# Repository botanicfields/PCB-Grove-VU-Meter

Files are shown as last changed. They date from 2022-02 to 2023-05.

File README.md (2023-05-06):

# PCB-Grove-VU-Meter
VU Meters into the Grove of M5

# オーディオレベルメーター用Grove(M5)接続基板
　ステレオオーディオ信号を、レベルメーター用のアナログ電圧信号に変換するプリント基板です。アナログ信号2本とM5Stack用の5V電源を、Groveコネクタから出力します。M5StackのLCDにVUメーターのように表示するサンプルプログラムを用意しています。

### サンプルプログラムの動作不良について
(2023/5/6) BF-037.inoは、以下の環境でコンパイルできました。しかしばがら、ADCによるオーディオ信号の取り込みが安定せず、使用に耐えない状況です。
- Arduino IDE 2.1.0
- Boards Manager:  
M5Stack by M5Stack official 2.0.7
- Library:  
M5Stack by M5Stack 0.4.3  
M5GFX 0.1.6

[内容物]  
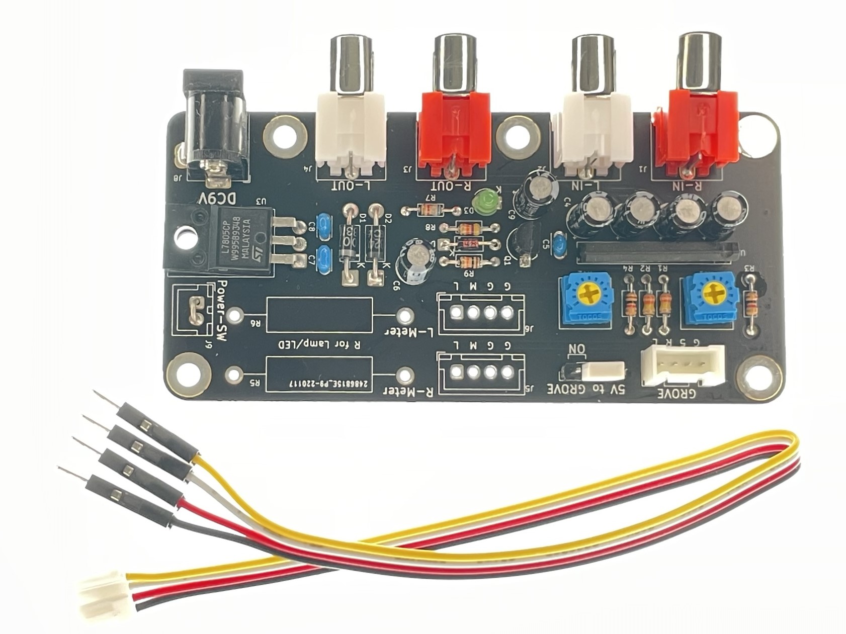
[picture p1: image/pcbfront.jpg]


動作例（YouTube）: [Audio level (VU/McIntosh) meters into the Grove of M5Stack](https://youtu.be/Pwd8X57_v_Q)

委託販売（スイッチサイエンス）:  [オーディオレベルメーター用Grove(M5)接続基板](https://www.switch-science.com/catalog/7947/)

## 安全上の注意事項
- 異常の場合、躊躇なくDCプラグを抜いてください（基板上のレギュレータ(U3)が触れないぐらい発熱しているなど）。その上で原因を取り除いてください。
- Groveへの5V出力は、必要な場合以外は、ジャンパピンJP3で切り離してください。特に電源が3.3Vの装置に5Vを供給すると焼損など事故の原因となります。
- 本基板からの5VとM5Stack側からの5Vは共存できません。僅かな電圧差から大電流が流れ、素子の発熱による火傷や、M5Stackの故障の原因になります。
- M5StackへのUSB-C以外の5V電源供給は推奨されていません。本基板の機能を含め、M5Stackへの直接の5V供給は自己責任です。

## 特徴
- オーディオ信号を整流し対数圧縮する専用LSI(ROHM BA6138)を使用しています。
- 基板上の半固定抵抗でフルスケールを調整できます。
- M5Stackの標準ボトムのピンソケットに接続するためのケーブルを添付しています。
- M5Stackへ5V電源を供給でき、スタンドアロン動作ができます。
- 左右2系統のRCAピンジャックが各々2個(In, Out)あり、RCAケーブルを中継できます。

## 注意事項
- 本基板は測定器ではありません。PCオーディオなどの手軽なオーディオ環境で見た目を楽しむための小物（ガジェット、ウィジェット、アクセサリ）です。サンプルプログラムの目盛も全くの飾りです。  
- BA6138は入力抵抗も2kΩ程度と低く、音質への影響は小さくないものと思われます。

## Groveコネクタへの5V電源供給のON/OFF
　本基板のジャンパピンJP3でGroveコネクタへの5V供給のON/OFFを設定します。JP3の切替は、DCプラグを抜いて実施ください。出荷時はOFFです。

| JP3 | Grove 5Vピン | M5Stackの電源 | 用途 |
|:-:|:- |:- |:- |
| OFF | 接続なし | USB-C、またはバッテリから供給(*1) | プログラム書き込み、シリアルモニターの利用など |
| ON  | 5Vを供給 | 本基板から供給(*2) | M5Stackをスタンドアロンで使用など |

(*1) JP3をOFFに設定してから、本基板のDCプラグを差し込んでください。  
(*2) JP3をONに設定する際は、USB-Cケーブルを取り外し、M5Stackを電源OFFとしてから、本基板のDCプラグを差し込んでください。バッテリ動作中のM5Stackは、電源/リセットボタンを2回押すことで電源OFFにできます。

[USB-C接続あり]  
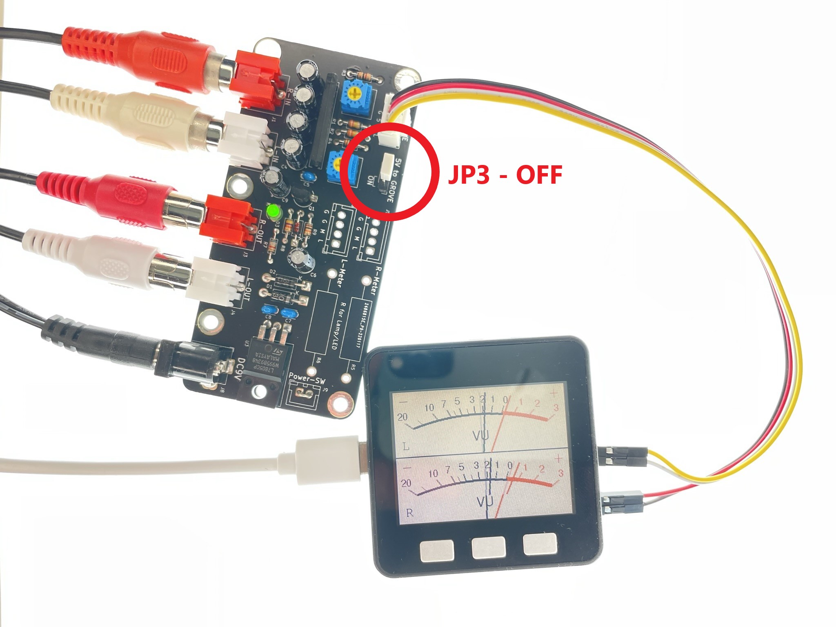
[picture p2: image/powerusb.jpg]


[Groveから電源供給]  
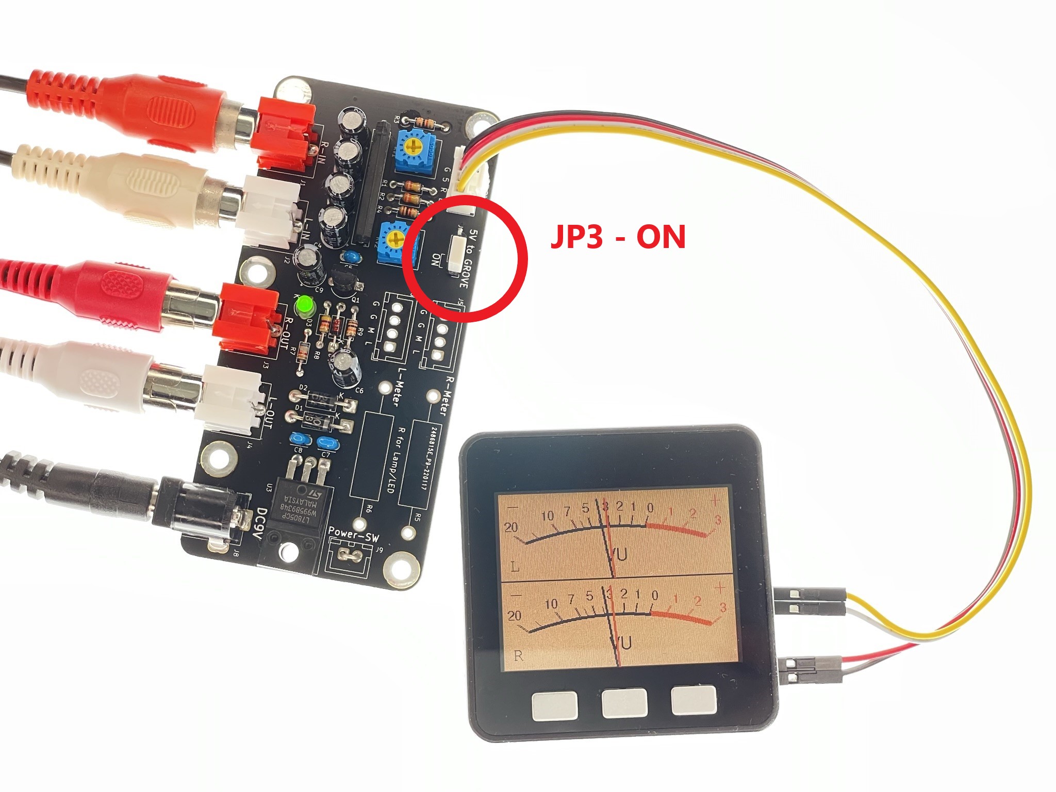
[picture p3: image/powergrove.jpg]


## 仕様
- 外形寸法: 92x44mm
- 電源入力: DCジャック（DC 9V）
- 信号入力: RCAピンジャック（L/R, オーディオラインレベル）
- 信号出力: Groveコネクタ（アナログ2本）
- 電源出力: Groveコネクタ（DC 5V）

## 内容物
- プリント基板（完成品）
- Grove-4ピン-ジャンパオスケーブル [SEEED-110990210](https://www.switch-science.com/catalog/6245/)　※5本入のうちの１本です
- 説明書

## 使用方法
- 電源（ACアダプタ等）は添付しません。別途ご用意ください。  
例：秋月電子通商　スイッチングＡＣアダプター　９Ｖ１．３Ａ [AD-B90P130](https://akizukidenshi.com/catalog/g/gM-11998/)
- 電源スイッチはありません。入力や出力を接続し、設定を確かめてからDCプラグを差し込んでください。
- RCAジャックは2系統（赤・白）あり、各々2個が並列になっています。便宜上、基板シルクにはIN, OUTと表示しています。
- Groveの出力信号はアナログ電圧です。M5StackのPort A(I2C)には接続できません。M5Stackのボトムの端子に接続してください。

[サンプルプログラム使用時のM5Stackへの接続]  
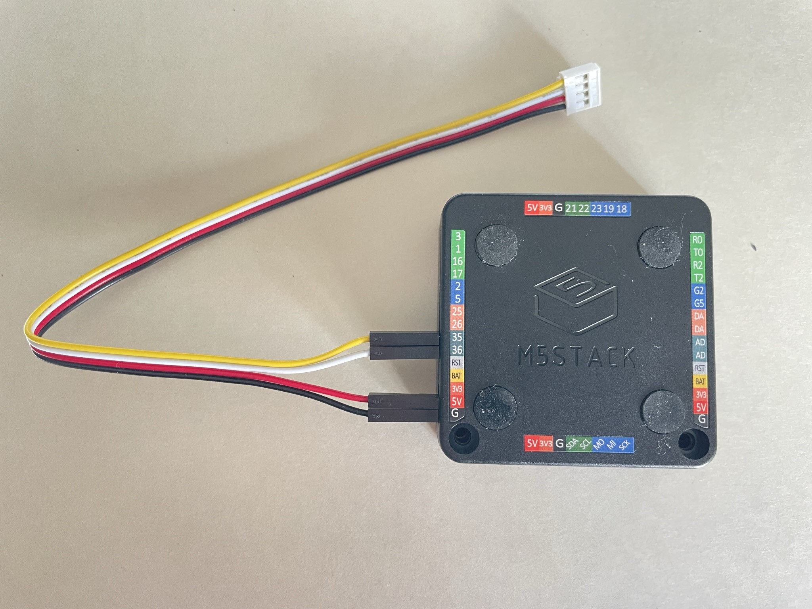
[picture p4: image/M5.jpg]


|Grove|M5Stack|
|:-:|:-:|
|L  |GPIO35|
|R  |GPIO36|
|5V |5V |
|GND|GND|

- 基板上の半固定抵抗は、ご使用の環境で再調整ください。調整には小型のプラスドライバが必要です。

### 出荷時の調整の環境
- Windows11
- USB DAC: Sound Blaster Digital Music Premium HD(SB1240) [製品情報](https://jp.creative.com/p/sound-blaster/sound-blaster-digital-music-premium-hd)  
※安定動作のためには、Windows10 64bit用ドライバーの適用が有効な様です。[ドライバーダウンロード](https://jp.creative.com/support/downloads/download.asp?Product_ID=19829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)
- YouTube Music: Audiolab 2014: Audio Test Tones: [1kHz 0dB](https://music.youtube.com/watch?v=_XMpb9BjGgE&feature=share)
- VUメーターが-5VUを示す様に調整（一般音源のメーターの振れが適当になる位置）

[入力信号-3dB(L/R)に対する出力(L/R)の例]  
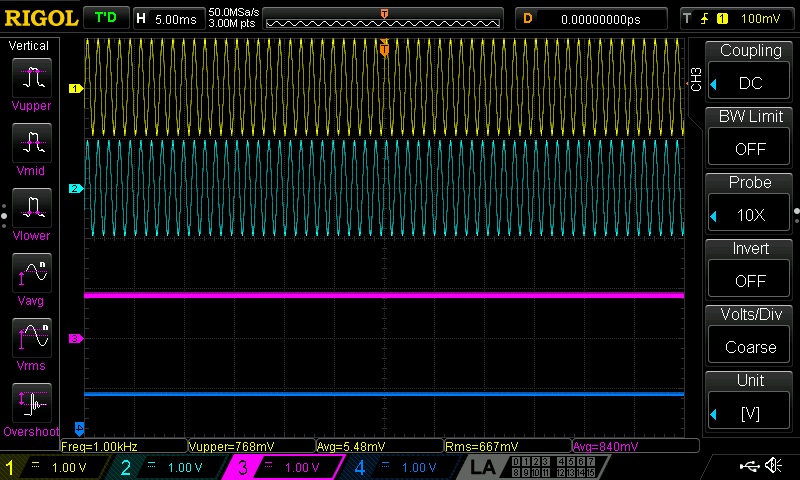
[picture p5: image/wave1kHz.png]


[音楽信号入力(L/R)に対する出力(L/R)の例]  
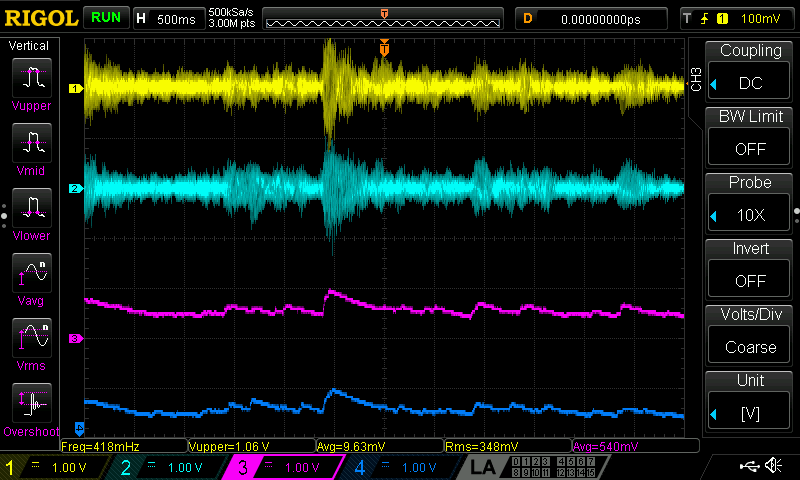
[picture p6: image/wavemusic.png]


## ご参考
- ROHM BA6138  
aitendo扱い レベルメーターアンプ [BA6138](https://www.aitendo.com/product/11726)
データシート[BA6138](http://aitendo3.sakura.ne.jp/aitendo_data/product_img/ic/audio/BA6138/BA6138.pdf)
- 基板上の、以下の部品等は未使用です。  
J5, J6, J9（短絡済）, JP1, JP2, R5, R6

[基板裏面]  
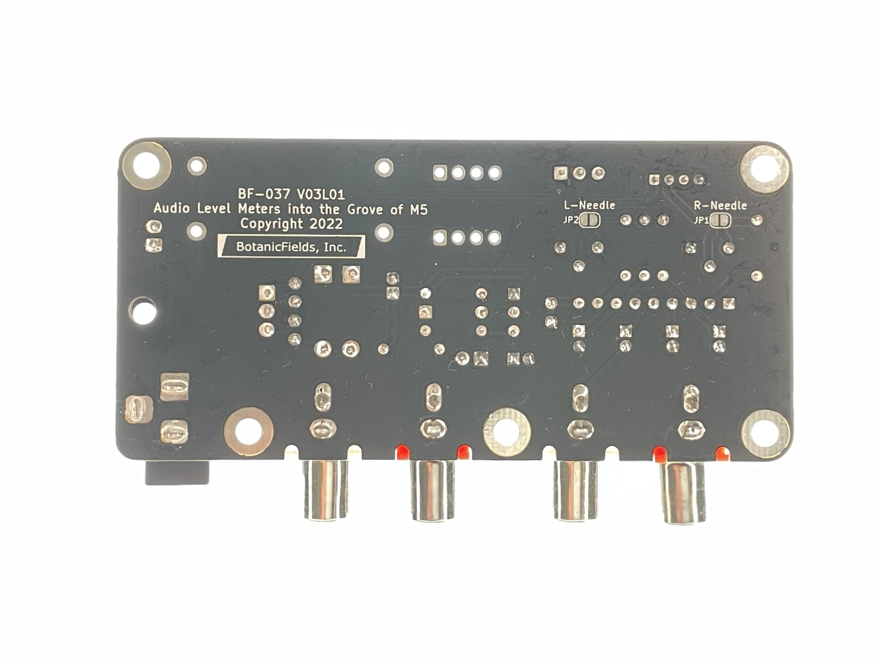
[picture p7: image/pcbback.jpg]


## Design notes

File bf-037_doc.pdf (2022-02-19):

BF-037 E01

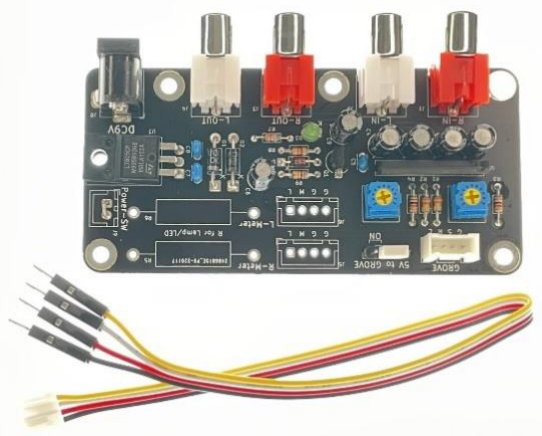
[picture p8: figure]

1 | Copyright 2022 BotanicFields, Inc.

## オーディオレベルメーター用 Grove(M5)接続基板

ステレオオーディオ信号を、レベルメーター用のアナログ 電圧信号に変換するプリント基板です。アナログ信号 2 本と M5Stack 用の 5V 電源を、Grove コネクタから出力します。

[サンプルプログラム、詳細情報]
https://github.com/botanicfields/PCB-Grove-VU-Meter

## 安全上の注意事項

⚫ | 異常の場合、躊躇なく DC プラグを抜いてください（基板上のレギュレータ(U3)が触れないぐ
| らい発熱しているなど）。その上で原因を取り除いてください。
⚫ | Grove への 5V 出力は、必要な場合以外は、ジャンパピン JP3 で切り離してください。特に電
| 源が 3.3V の装置に 5V を供給すると焼損など事故の原因となります。
⚫ | 本基板からの 5Vと M5Stack 側からの 5Vは共存できません。僅かな電圧差から大電流が流れ、
| 素子の発熱による火傷や M5Stack の故障の原因になります。
⚫ | M5StackへのUSB-C以外の5V電源供給は推奨されていません。本基板の機能を含め、M5Stack
| への直接の 5V 供給は自己責任です。
1. 仕様
⚫ | 外形寸法: 92x44mm
⚫ | 電源入力: DC ジャック（DC 9V）
⚫ | 信号入力: RCA ピンジャック（L/R, オーディオラインレベル）
⚫ | 信号出力: Grove コネクタ（アナログ 2 本）
⚫ | 電源出力: Grove コネクタ（DC 5V）
2. 内容物
⚫ | プリント基板（完成品）
⚫ | Grove-4 ピン-ジャンパオスケーブル
⚫ | 説明書（本書）
3. 使用方法
⚫ | 電源（AC アダプタ等）は添付しません。別途ご用意ください。
| （例）秋月電子通商 M-11998 スイッチングＡＣアダプター ９Ｖ１．３Ａ [AD-B90P130]
⚫ | 電源スイッチはありません。入力や出力を接続し、設定を確かめてから DC プラグを差し込ん
| でください。
⚫ | RCA ジャックは 2 系統（赤・白）あり、各々2 個が並列になっています。便宜上、基板シルク

BF-037 E01

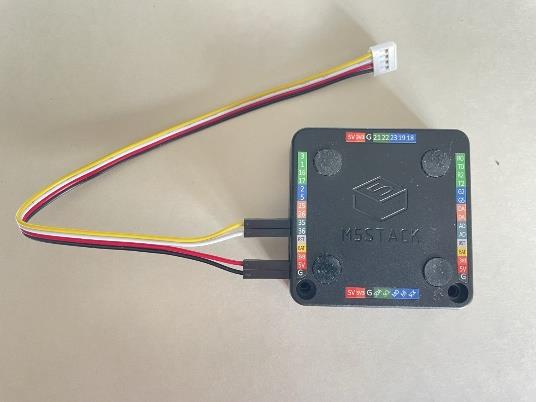
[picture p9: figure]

2 | Copyright 2022 BotanicFields, Inc.

には IN, OUT と表示しています。
⚫ | Grove の出力信号はアナログ電圧です。M5Stack の Port A(I2C)には接続できません。M5Stack
| のボトムの端子に接続してください。
⚫ | Grove コネクタへの 5V 電源供給の ON/OFF は、ジャンパピン JP3 で設定します。JP3 の設定
| 変更は、DC プラグを抜いて実施ください。出荷時は OFF です。
JP3 | Grove 5V ピン | M5Stack の電源 | 用途
OFF | 接続なし | USB-C、またはバッテリから 供給(*1) | プログラムの書き込み、シリアルモニ ターの利用など
ON | 5V を供給 | 本基板から供給(*2) | M5Stack をスタンドアロンで使用など

(*1) JP3 を OFF に設定してから、本基板の DC プラグを差し込んでください。
(*2) JP3 を ON に設定する際は、USB-C ケーブルを取り外し、M5Stack を電源 OFF としてから、本基 板の DC プラグを差し込んでください。バッテリ動作中の M5Stack は、電源/リセットボタンを 2 回押 すことで電源 OFF にできます。

[サンプルプログラム使用時の接続]
右の表に従って、添付のケーブルを
M5Stack のボトムの端子に接続してく
ださい。

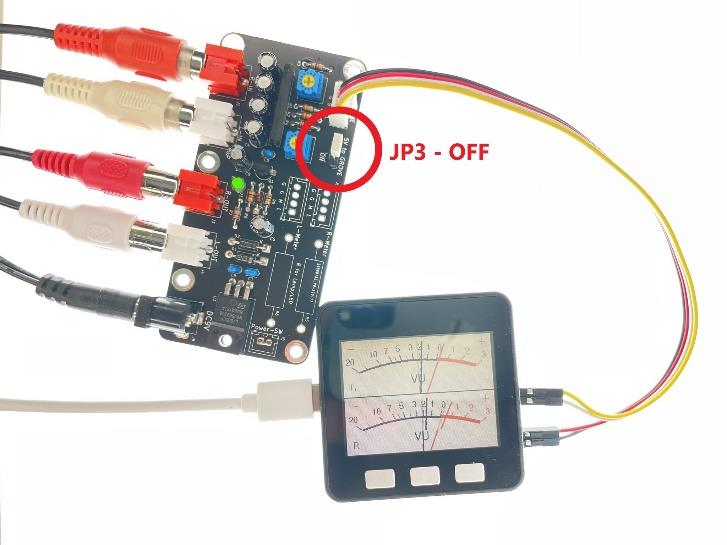
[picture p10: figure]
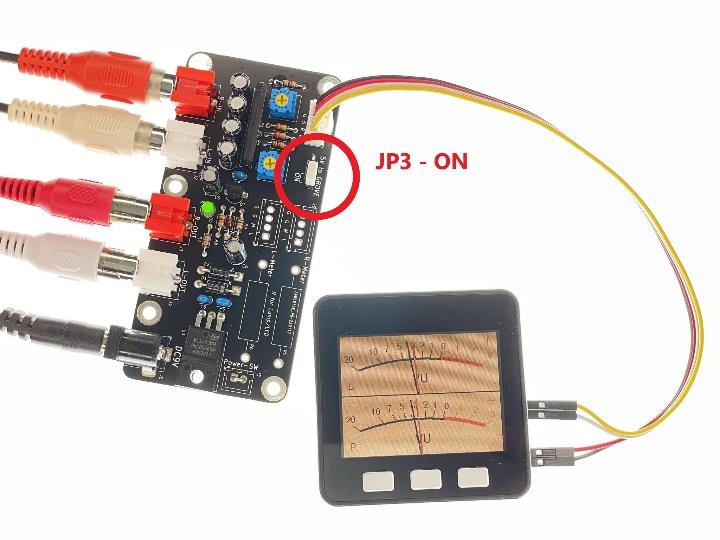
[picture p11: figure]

[USB-C 接続時の設定] | [Grove から 5V を供給する設定]

以上

Grove | M5Stack
L R 5V GND | GPIO35
| GPIO36
| 5V
| GND

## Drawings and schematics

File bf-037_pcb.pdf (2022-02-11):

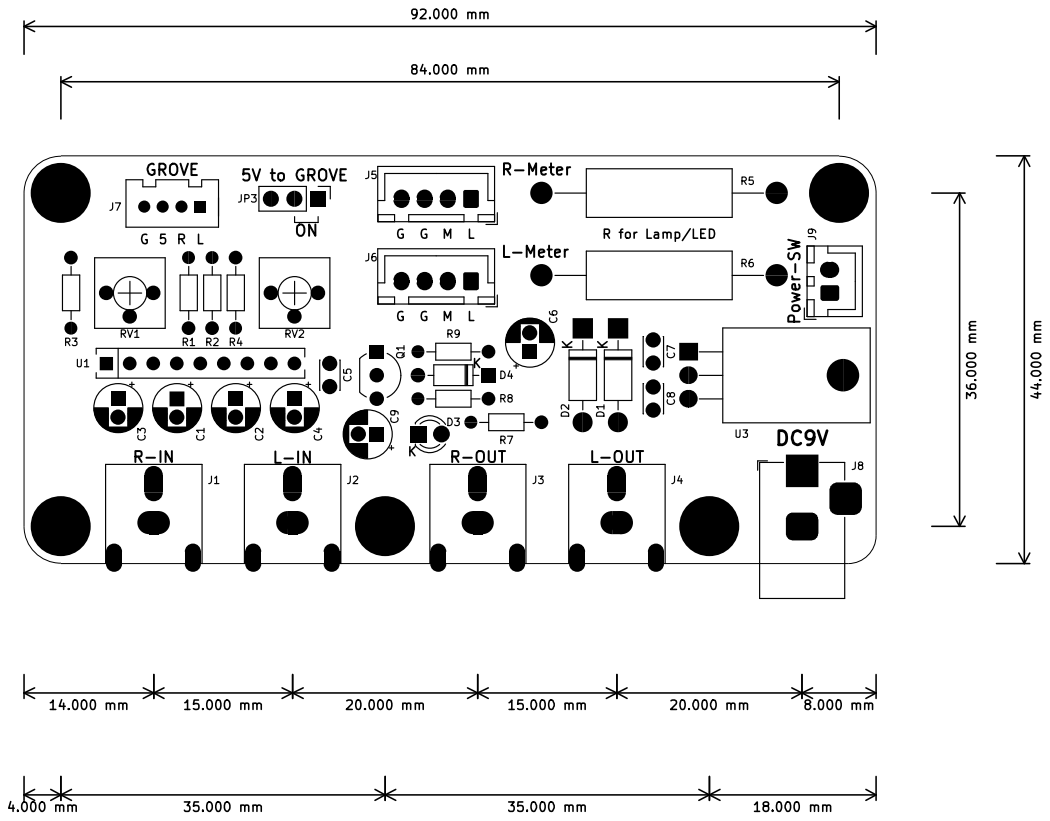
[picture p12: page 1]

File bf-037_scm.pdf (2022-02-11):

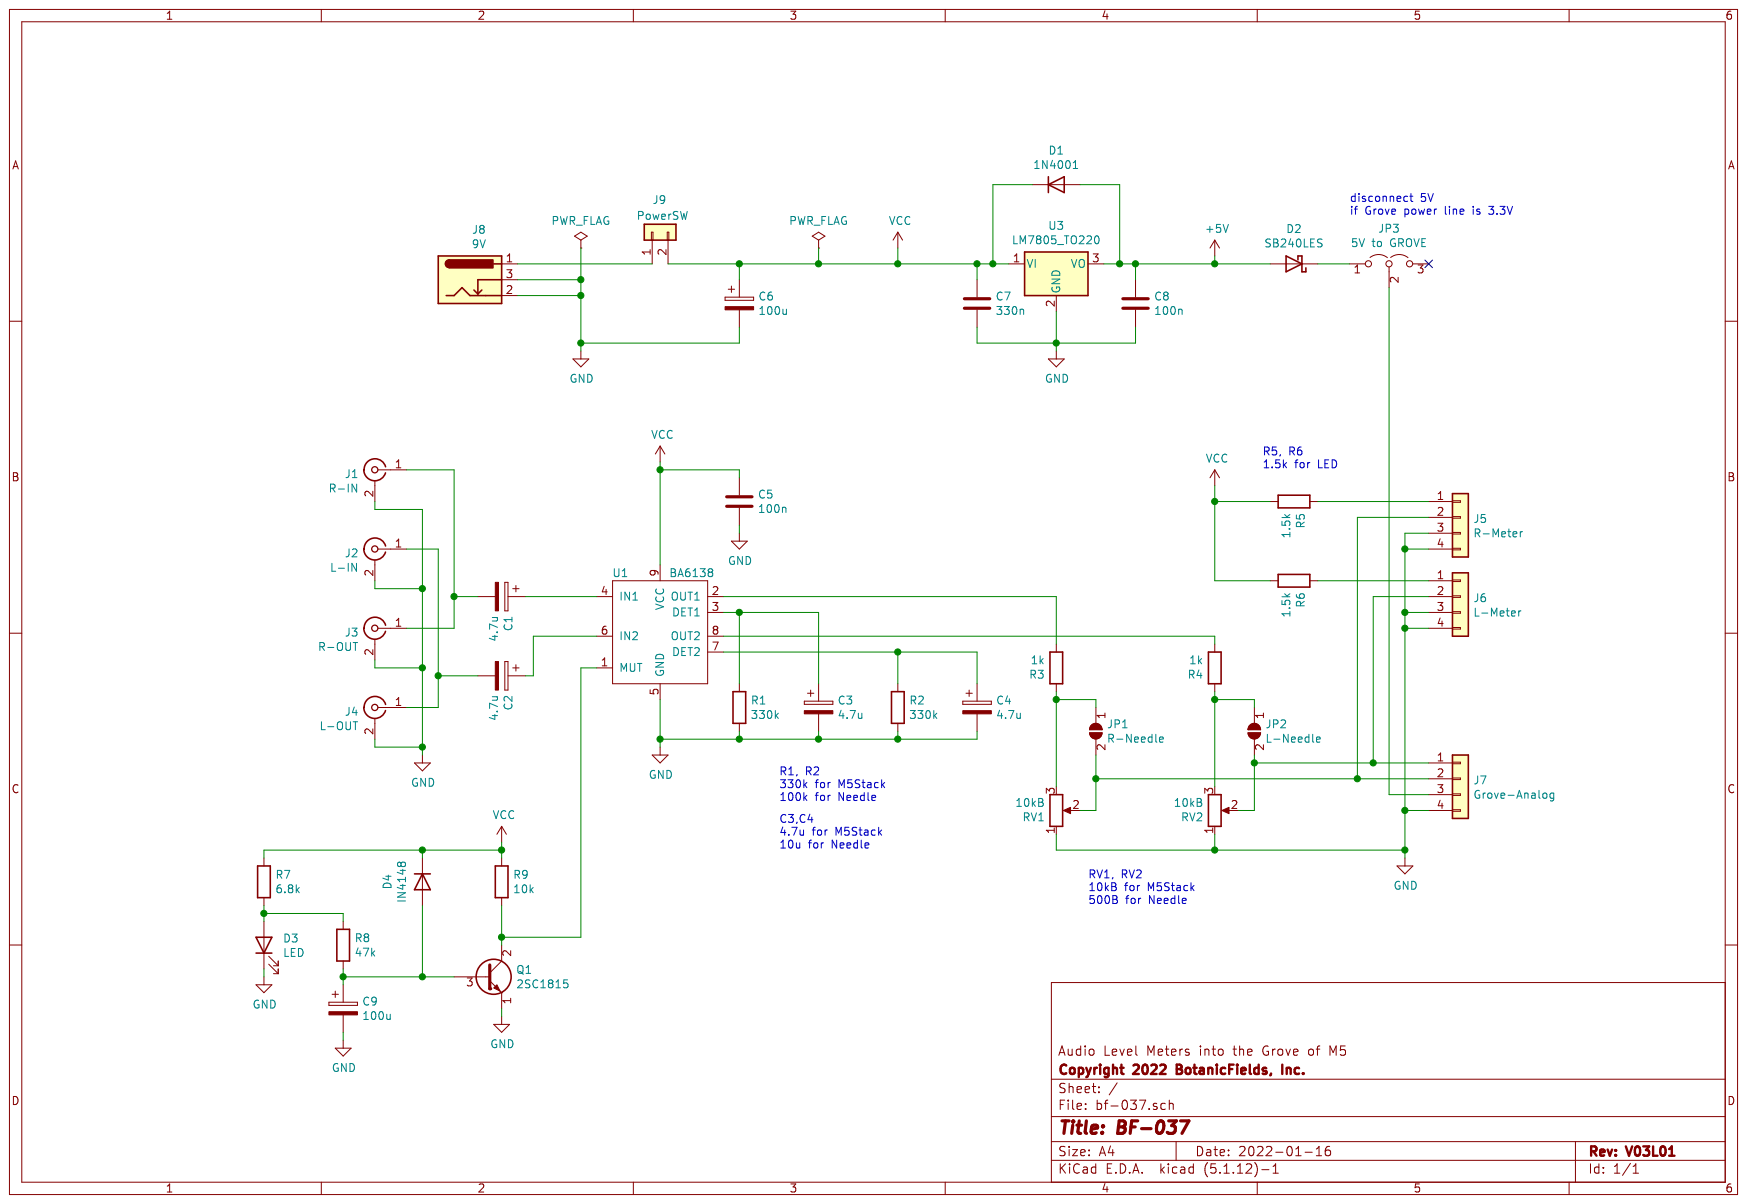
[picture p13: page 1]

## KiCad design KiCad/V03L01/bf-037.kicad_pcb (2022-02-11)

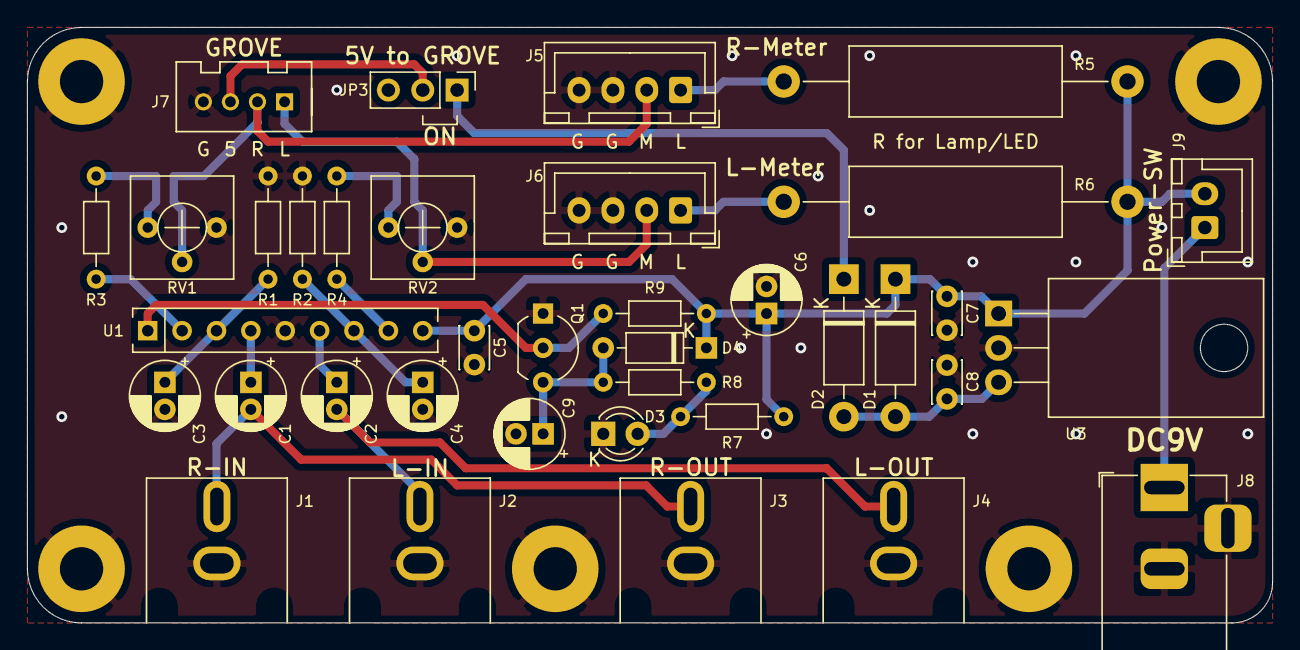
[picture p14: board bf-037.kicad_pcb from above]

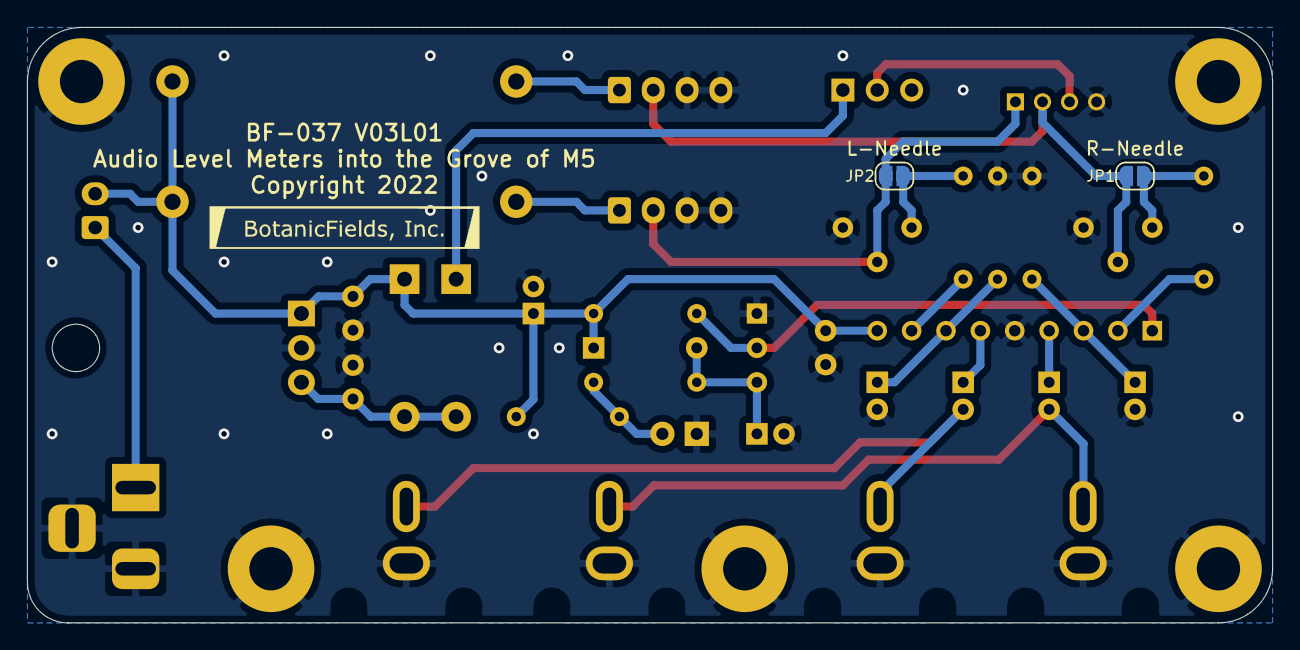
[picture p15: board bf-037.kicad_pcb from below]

Board: 2 copper layers, 92.0 x 44.0 mm, 39 parts (2 on the bottom side), 23 nets.

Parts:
C1, C2, C3, C4: 4.7u; CP_Radial_D5.0mm_P2.00mm
C5, C8: 100n; C_Disc_D3.0mm_W2.0mm_P2.50mm
C6, C9: 100u; CP_Radial_D5.0mm_P2.00mm
C7: 330n; C_Disc_D3.0mm_W2.0mm_P2.50mm
D1: 1N4001; D_DO-41_SOD81_P10.16mm_Horizontal
D2: SB240LES; D_DO-41_SOD81_P10.16mm_Horizontal
D3: LED; LED_D3.0mm
D4: IN4148; D_DO-35_SOD27_P7.62mm_Horizontal
J1: R-IN; BF@RCA-2P-XINA
J2: L-IN; BF@RCA-2P-XINA
J3: R-OUT; BF@RCA-2P-XINA
J4: L-OUT; BF@RCA-2P-XINA
J5: R-Meter; JST_XH_B4B-XH-A_1x04_P2.50mm_Vertical
J6: L-Meter; JST_XH_B4B-XH-A_1x04_P2.50mm_Vertical
J7: Grove-Analog; HW4-2.0
J8: 9V; BF@BarrelJack_Horizontal
J9: PowerSW; JST_XH_B2B-XH-A_1x02_P2.50mm_Vertical
JP1: R-Needle; SolderJumper-2_P1.3mm_Open_RoundedPad1.0x1.5mm
JP2: L-Needle; SolderJumper-2_P1.3mm_Open_RoundedPad1.0x1.5mm
JP3: 5V to GROVE; PinHeader_1x03_P2.54mm_Vertical
Q1: 2SC1815; TO-92_Inline_Wide
R1, R2: 330k; R_Axial_DIN0204_L3.6mm_D1.6mm_P7.62mm_Horizontal
R3, R4: 1k; R_Axial_DIN0204_L3.6mm_D1.6mm_P7.62mm_Horizontal
R5, R6: 1.5k; R_Axial_DIN0516_L15.5mm_D5.0mm_P25.40mm_Horizontal
R7: 6.8k; R_Axial_DIN0204_L3.6mm_D1.6mm_P7.62mm_Horizontal
R8: 47k; R_Axial_DIN0204_L3.6mm_D1.6mm_P7.62mm_Horizontal
R9: 10k; R_Axial_DIN0204_L3.6mm_D1.6mm_P7.62mm_Horizontal
RV1, RV2: 10kB; BF@BOURNS3362P
U1: BA6138; SIP-9_22.3x3mm_P2.54mm
U3: LM7805_TO220; TO-220-3_Horizontal_TabDown

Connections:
+5V: C8.1, D1.2, D2.2, U3.3
GND: C3.2, C4.2, C5.2, C6.2, C7.2, C8.2, C9.2, D3.1, J1.2, J2.2, J3.2, J4.2, J5.3, J5.4, J6.3, J6.4, J7.4, J8.2, J8.3, Q1.1, R1.2, R2.2, RV1.1, RV2.1, U1.5, U3.2
unnamed: C1.1, U1.4
unnamed: C1.2, J1.1, J3.1
unnamed: C2.1, U1.6
unnamed: C2.2, J2.1, J4.1
unnamed: C3.1, R1.1, U1.3
unnamed: C4.1, R2.1, U1.7
unnamed: C9.1, D4.2, Q1.3, R8.2
unnamed: D2.1, JP3.1
unnamed: D3.2, R7.2, R8.1
unnamed: J5.1, R5.1
unnamed: J5.2, J7.2, JP1.2, RV1.2
unnamed: J6.1, R6.1
unnamed: J6.2, J7.1, JP2.2, RV2.2
unnamed: J7.3, JP3.2
unnamed: J8.1, J9.1
unnamed: JP1.1, R3.1, RV1.3
unnamed: JP2.1, R4.1, RV2.3
unnamed: Q1.2, R9.2, U1.1
unnamed: R3.2, U1.2
unnamed: R4.2, U1.8
VCC: C5.1, C6.1, C7.1, D1.1, D4.1, J9.2, R5.2, R6.2, R7.1, R9.1, U1.9, U3.1

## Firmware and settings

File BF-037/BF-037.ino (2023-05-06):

// Copyright 2022 BotanicFields, Inc.
// BF-037 VU meters on M5Stack

#include <M5Stack.h>
#include "BF_M5StackVuMeter.h"

// for control loop
const unsigned int loop_ms(50);  // 20fps
      unsigned int last_ms(0);

// for meters
const int offset(142);  // offset 142mV at ground-level on ESP32 ADC
const int vu_0(1227);   // 0VU = 1227mV

const int time_attack_vu(1000);    // 1000ms for attacking from -20VU to 0VU
const int time_attack_mc(3000);    // 3000ms for attacking from -60VU to 0dB
const int time_return_peak(8000);  // 8000ms for recovery from 0VU to -20VU

int vu_step   = vu_0 / (time_attack_vu   / loop_ms);
int peak_step = vu_0 / (time_return_peak / loop_ms);

int last_vu_left(0);
int last_vu_right(0);
int last_peak_left(0);
int last_peak_right(0);

enum meter_style_enum { vu_meter = 0, mc_meter };
meter_style_enum meter_style(vu_meter);

enum ch_select_enum { stereo = 0, left_ch, right_ch };
ch_select_enum ch_select(stereo);

bool double_needle(true);

void setup()
{
  const bool lcd_enable(true);
  const bool sd_enable(true);
  const bool serial_enable(true);
  const bool i2c_enable(true);
  M5.begin(!lcd_enable, !sd_enable, serial_enable, i2c_enable);

  // analog to digital converter
  analogReadResolution(12);
  analogSetAttenuation(ADC_11db);

  // lcd & meter
  lcd_init();
  switch (meter_style) {
  case mc_meter:
    make_panel_mc();
    vu_step = vu_0 / (time_attack_mc / loop_ms);
    double_needle = false;
    break;
  case vu_meter:
  default:
    make_panel_vu();
    vu_step = vu_0 / (time_attack_vu / loop_ms);
    double_needle = true;
    meter_style = vu_meter;
    break;
  }

  // loop control
  last_ms = millis();
}

void loop()
{
  // button control
  M5.update();
  if (M5.BtnA.wasReleased()) {
    switch (meter_style) {
    case vu_meter:
      meter_style = mc_meter;
      make_panel_mc();
      vu_step = vu_0 / (time_attack_mc / loop_ms);
      double_needle = false;
      break;
    case mc_meter:
    default:
      meter_style = vu_meter;
      make_panel_vu();
      vu_step = vu_0 / (time_attack_vu / loop_ms);
      double_needle = true;
      break;
    }
    last_ms = millis();  // avoid loop hangs
  }
  if (M5.BtnB.wasReleased()) {
    switch (ch_select) {
    case stereo:
      ch_select = left_ch;
      break;
    case left_ch:
      ch_select = right_ch;
      break;
    case right_ch:
    default:
      ch_select = stereo;
      break;
    }
    lcd_clear();
    last_ms = millis();  // avoid loop hangs
  }
  if (M5.BtnC.wasReleased()) {
    double_needle = !double_needle;
  }

  // read ADC
  int adc_7 = analogReadMilliVolts(35);
  int adc_0 = analogReadMilliVolts(36);

  // compensation of ESP32 ADC
  adc_7 = (adc_7 - offset) * vu_0 / (vu_0 - offset);
  adc_0 = (adc_0 - offset) * vu_0 / (vu_0 - offset);

  // response
  if (adc_7 > last_vu_left    + vu_step)   last_vu_left    += vu_step;   else last_vu_left    = adc_7;
  if (adc_0 > last_vu_right   + vu_step)   last_vu_right   += vu_step;   else last_vu_right   = adc_0;
  if (adc_7 < last_peak_left  - peak_step) last_peak_left  -= peak_step; else last_peak_left  = adc_7;
  if (adc_0 < last_peak_right - peak_step) last_peak_right -= peak_step; else last_peak_right = adc_0;

  // draw meter on LCD
  if (double_needle)
    switch (ch_select) {
    case left_ch:
      show_meter(0,   0, "L", last_vu_left, last_peak_left);
      break;
    case right_ch:
      show_meter(0,   0, "R", last_vu_right, last_peak_right);
      break;
    case stereo:
    default:
      show_meter(0,   0, "L", last_vu_left, last_peak_left);
      show_meter(0, 120, "R", last_vu_right, last_peak_right);
      break;
    }
  else
    switch (ch_select) {
    case left_ch:
      show_meter(0,   0, "L", last_vu_left);
      break;
    case right_ch:
      show_meter(0,   0, "R", last_vu_right);
      break;
    case stereo:
    default:
      show_meter(0,   0, "L", last_vu_left);
      show_meter(0, 120, "R", last_vu_right);
      break;
    }

  // loop control
  Serial.printf("elapse=%dms adc7=%d adc0=%d\n", millis() - last_ms, adc_7, adc_0);  // elapsed time
  delay(last_ms + loop_ms - millis());
  last_ms = millis();
}

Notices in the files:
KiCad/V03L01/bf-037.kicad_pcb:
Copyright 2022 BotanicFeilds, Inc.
